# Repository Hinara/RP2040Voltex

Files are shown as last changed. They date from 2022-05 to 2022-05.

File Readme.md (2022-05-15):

# RP2040Voltex

Work in progress !! The PCB nor the schematics have been tested for now !! It is just a proof of concept !

It is a mini controller for games such as Sound Voltex, and clones.

This model is based on [Pocket-SDVX-Pico](https://github.com/speedypotato/Pocket-SDVX-Pico-v4)
The Lower PCB should be compatible [Pocket-SDVX-Pico](https://github.com/speedypotato/Pocket-SDVX-Pico-v4)

It's main difference is using directly a RP2040 processor to be able to meet the height constraints on the upper face. This was designed like that to prevent ripping of some Pico's component while putting the Pocket SDVX Pico in a bag without a case.

## Firmware

For now the firmware as not been updated to math the RP2040 pin layout, but you should be able to have a working firmware by compiling the [Pocket-SDVX-Pico](https://github.com/speedypotato/Pico-Game-Controller) firmware and change the pin layout.

## License

As it is derived work from [Pocket-SDVX-Pico](https://github.com/speedypotato/Pocket-SDVX-Pico-v4) it inherits the same [license](https://github.com/speedypotato/Pocket-SDVX-Pico-v4/blob/main/LICENSE).

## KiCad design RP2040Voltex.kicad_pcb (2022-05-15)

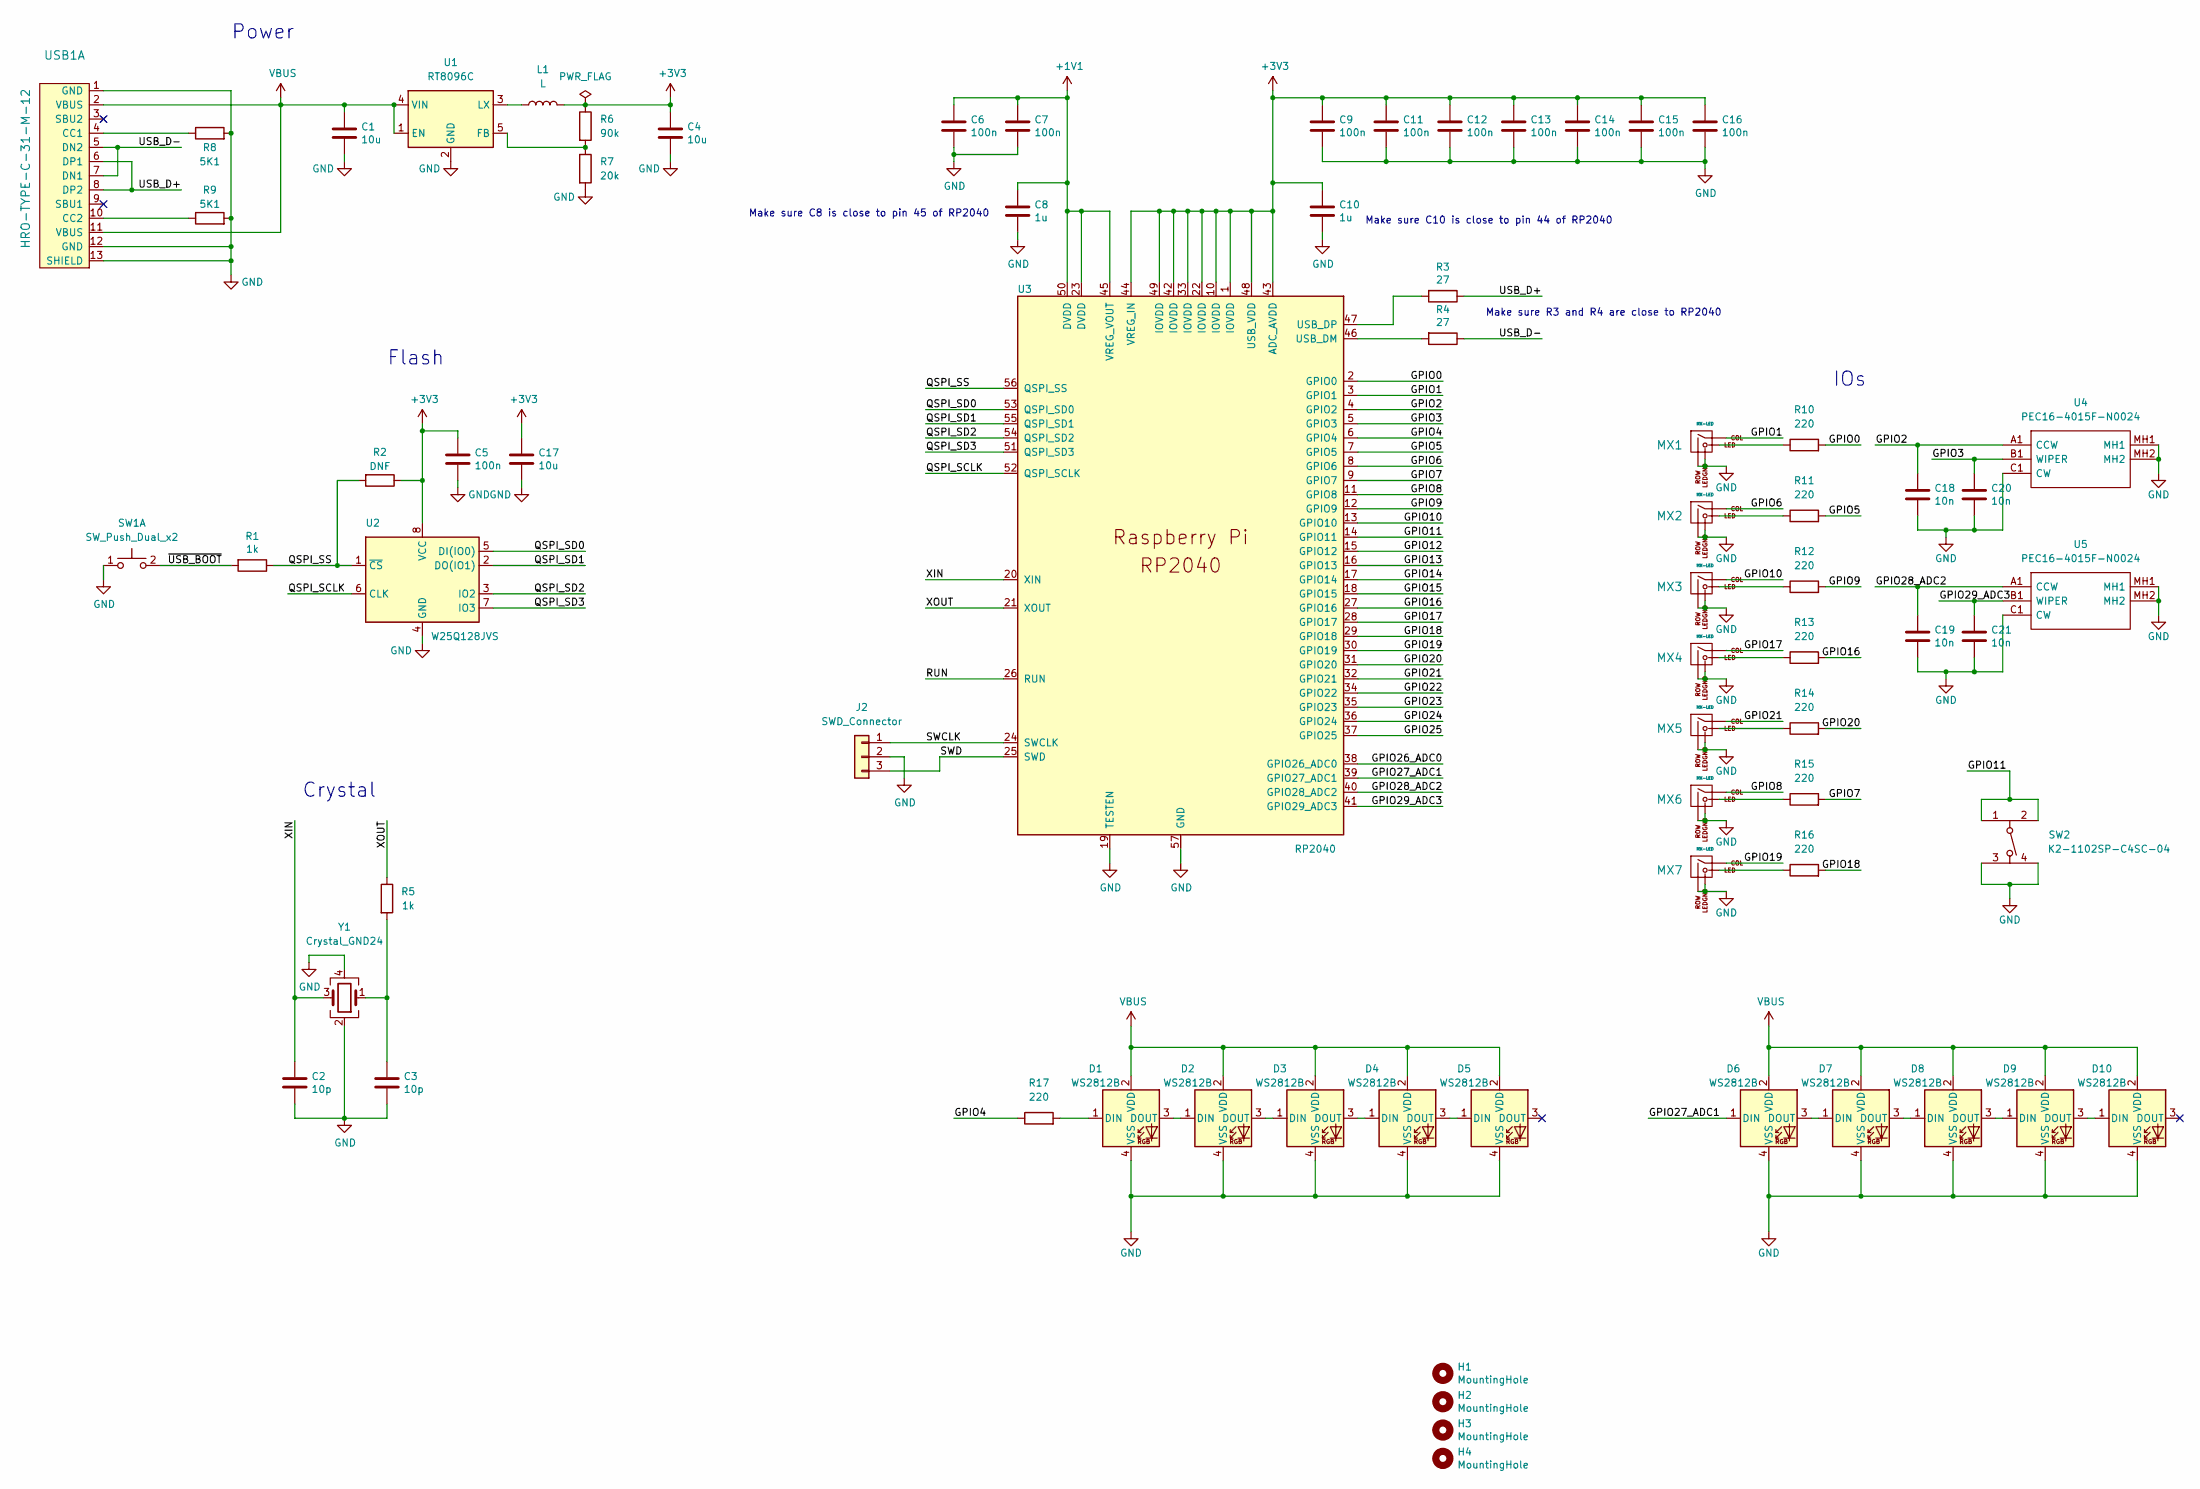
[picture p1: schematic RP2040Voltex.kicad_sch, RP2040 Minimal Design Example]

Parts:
C1: 10u; L_1008_2520Metric
C2, C3: 10p; C_0402_1005Metric
C4, C17: 10u; C_0805_2012Metric
C5, C6, C7, C9, C11, C12, C13, C14, C15, C16: 100n; C_0402_1005Metric
C8, C10: 1u; C_0402_1005Metric
C18, C19, C20, C21: 10n; C_0603_1608Metric
D1, D2, D3, D4, D5, D6, D7, D8, D9, D10: WS2812B; WS2812B-4020
H1, H2, H3, H4: MountingHole; MountingHole_3.2mm_M3
J2: SWD_Connector
L1: L; L_1008_2520Metric
MX1, MX2, MX3, MX4, MX5, MX6, MX7: MX-LED; MXOnly-1.5U-Hotswap-LED-SMD
R1, R5: 1k; R_0402_1005Metric
R2: DNF; R_0402_1005Metric
R3, R4: 27; R_0402_1005Metric
R6: 90k; R_0402_1005Metric
R7: 20k; R_0402_1005Metric
R8, R9: 5K1; R_0603_1608Metric
R10, R11, R12, R13, R14, R15, R16, R17: 220; R_0603_1608Metric
SW1: SW_Push_Dual_x2; TS-1012A
SW2: K2-1102SP-C4SC-04; KAN4542-0701C
U1: RT8096C; TSOT-23-5
U2: W25Q128JVS; SOIC-8_5.23x5.23mm_P1.27mm
U3: RP2040; RP2040-QFN-56
U4, U5: PEC16-4015F-N0024; PEC16-4015F-N0024-millmax; Mouser Part Number 652-PEC16-4015FN0024
USB1: HRO-TYPE-C-31-M-12; HRO-TYPE-C-31-M-12-Assembly
Y1: Crystal_GND24; Crystal_SMD_2520-4Pin_2.5x2.0mm

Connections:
+1V1: C6.1, C7.1, C8.1, U3.23 (DVDD), U3.45 (VREG_VOUT), U3.50 (DVDD)
+3V3: C4.1, C5.1, C9.1, C10.1, C11.1, C12.1, C13.1, C14.1, C15.1, C16.1, C17.1, L1.2, R2.1, R6.1, U2.8 (VCC), U3.1 (IOVDD), U3.10 (IOVDD), U3.22 (IOVDD), U3.33 (IOVDD), U3.42 (IOVDD), U3.43 (ADC_AVDD), U3.44 (VREG_IN), U3.48 (USB_VDD), U3.49 (IOVDD)
/GPIO0: R10.2, U3.2 (GPIO0)
/GPIO1: MX1.1 (COL), U3.3 (GPIO1)
/GPIO2: C18.1, U3.4 (GPIO2), U4.A1 (CCW)
/GPIO3: C20.1, U3.5 (GPIO3), U4.B1 (WIPER)
/GPIO4: R17.1, U3.6 (GPIO4)
/GPIO5: R11.2, U3.7 (GPIO5)
/GPIO6: MX2.1 (COL), U3.8 (GPIO6)
/GPIO7: R15.2, U3.9 (GPIO7)
/GPIO8: MX6.1 (COL), U3.11 (GPIO8)
/GPIO9: R12.2, U3.12 (GPIO9)
/GPIO10: MX3.1 (COL), U3.13 (GPIO10)
/GPIO11: SW2.1, SW2.2, U3.14 (GPIO11)
/GPIO12: U3.15 (GPIO12)
/GPIO13: U3.16 (GPIO13)
/GPIO14: U3.17 (GPIO14)
/GPIO15: U3.18 (GPIO15)
/GPIO16: R13.2, U3.27 (GPIO16)
/GPIO17: MX4.1 (COL), U3.28 (GPIO17)
/GPIO18: R16.2, U3.29 (GPIO18)
/GPIO19: MX7.1 (COL), U3.30 (GPIO19)
/GPIO20: R14.2, U3.31 (GPIO20)
/GPIO21: MX5.1 (COL), U3.32 (GPIO21)
/GPIO22: U3.34 (GPIO22)
/GPIO23: U3.35 (GPIO23)
/GPIO24: U3.36 (GPIO24)
/GPIO25: U3.37 (GPIO25)
/GPIO26_ADC0: U3.38 (GPIO26_ADC0)
/GPIO27_ADC1: D6.1 (DIN), U3.39 (GPIO27_ADC1)
/GPIO28_ADC2: C19.1, U3.40 (GPIO28_ADC2), U5.A1 (CCW)
/GPIO29_ADC3: C21.1, U3.41 (GPIO29_ADC3), U5.B1 (WIPER)
/QSPI_SCLK: U2.6 (CLK), U3.52 (QSPI_SCLK)
/QSPI_SD0: U2.5 (DI(IO0)), U3.53 (QSPI_SD0)
/QSPI_SD1: U2.2 (DO(IO1)), U3.55 (QSPI_SD1)
/QSPI_SD2: U2.3 (IO2), U3.54 (QSPI_SD2)
/QSPI_SD3: U2.7 (IO3), U3.51 (QSPI_SD3)
/QSPI_SS: R1.1, R2.2, U2.1 (~CS), U3.56 (QSPI_SS)
/RUN: U3.26 (RUN)
/SWCLK: J2.1 (SWCLK), U3.24 (SWCLK)
/SWD: J2.3 (SWDIO), U3.25 (SWD)
/USB_D+: R3.1, USB1.6 (DP1), USB1.8 (DP2)
/USB_D-: R4.1, USB1.5 (DN2), USB1.7 (DN1)
/XIN: C2.1, U3.20 (XIN), Y1.3
/XOUT: R5.1, U3.21 (XOUT)
/~USB_BOOT: R1.2, SW1.2 (D)
unnamed: C3.1, R5.2, Y1.1
unnamed: D1.1 (DIN), R17.2
unnamed: D1.3 (DOUT), D2.1 (DIN)
unnamed: D2.3 (DOUT), D3.1 (DIN)
unnamed: D3.3 (DOUT), D4.1 (DIN)
unnamed: D4.3 (DOUT), D5.1 (DIN)
unnamed: D6.3 (DOUT), D7.1 (DIN)
unnamed: D7.3 (DOUT), D8.1 (DIN)
unnamed: D8.3 (DOUT), D9.1 (DIN)
unnamed: D9.3 (DOUT), D10.1 (DIN)
unnamed: L1.1, U1.3 (LX)
unnamed: MX1.3 (LED), R10.1
unnamed: MX2.3 (LED), R11.1
unnamed: MX3.3 (LED), R12.1
unnamed: MX4.3 (LED), R13.1
unnamed: MX5.3 (LED), R14.1
unnamed: MX6.3 (LED), R15.1
unnamed: MX7.3 (LED), R16.1
unnamed: R3.2, U3.47 (USB_DP)
unnamed: R4.2, U3.46 (USB_DM)
unnamed: R6.2, R7.1, U1.5 (FB)
unnamed: R8.1, USB1.4 (CC1)
unnamed: R9.1, USB1.10 (CC2)

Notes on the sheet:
Make sure C10 is close to pin 44 of RP2040
Make sure C8 is close to pin 45 of RP2040
Crystal
Make sure R3 and R4 are close to RP2040
Flash
Power
IOs

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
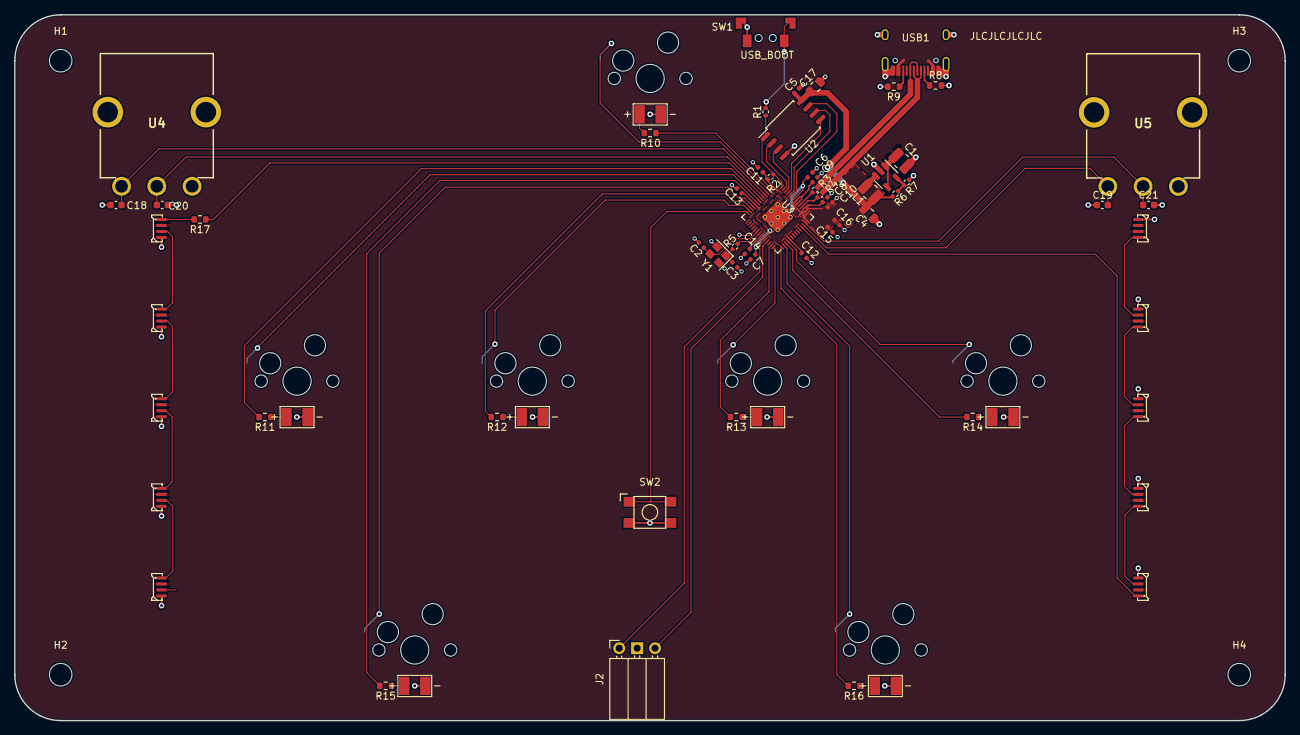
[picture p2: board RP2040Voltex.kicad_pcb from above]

Board: 2 copper layers, 180.0 x 100.0 mm, 70 parts (0 on the bottom side), 61 nets.

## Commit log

2022-05-15 First Version of RP2040Voltex
    [RP2040Voltex.kicad_pcb, RP2040Voltex.kicad_sch]
2022-05-15 Make capacitor closer to encoders
    [RP2040Voltex.kicad_pcb]
2022-05-15 Change front plane to be power plane
    [RP2040Voltex.kicad_pcb]
2022-05-15 Split led strips + Put usb boot underneath
    [RP2040Voltex.kicad_pcb, RP2040Voltex.kicad_sch]
